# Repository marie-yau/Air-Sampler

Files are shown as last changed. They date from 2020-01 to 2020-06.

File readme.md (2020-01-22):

# Next-Generation Air Sampler Project

This project seeks to design a lightweight, programmable air sampler.

The sampler will be constructed on the
[Raspberry Pi](https://www.raspberrypi.org/)
platform.

The sampler will allow for the automated operation of an air pump and any number of three-way solenoids.

Its immediate use is for tracer gas experiments in which bags will be used to capture samples of air outdoors or in buildings.

The project is led in parts by Michael Sohn (Principal Investigator),
Woody Delp,
David Lorenzetti,
Randy Maddelena,
Marion Russell,
and
Marie Yau.

The project is supported in part by the Defense Threat Reduction Agency.

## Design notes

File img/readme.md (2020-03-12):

# Circuit Diagrams

This folder contains circuit diagrams for the setup of the sampler and of any additional modules of Raspberry Pi.

The files with ```.fzz``` extension can be opened using [Fritzing](https://fritzing.org/home/), a software used for the creation of diagrams.

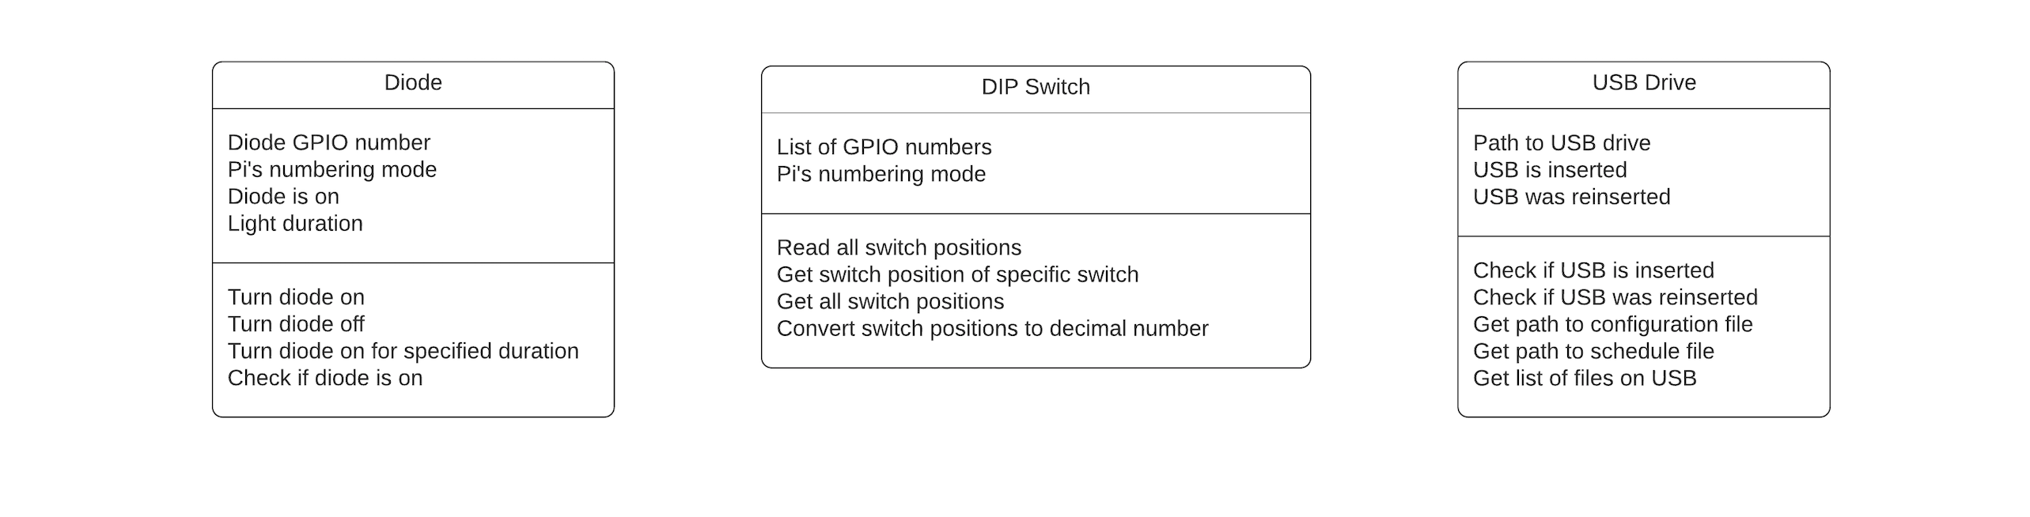
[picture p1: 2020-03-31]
img/UML_hardware.png

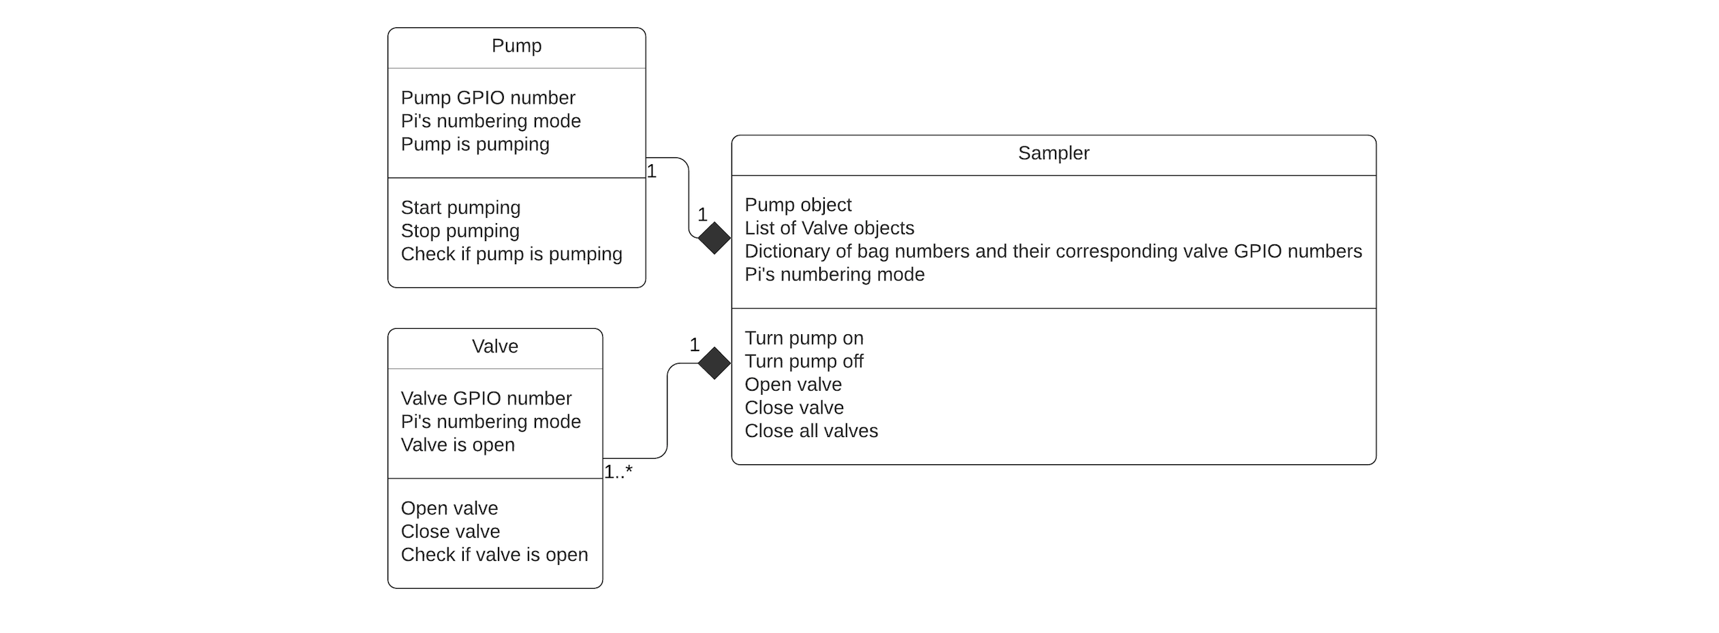
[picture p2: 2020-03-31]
img/UML_sampler.png

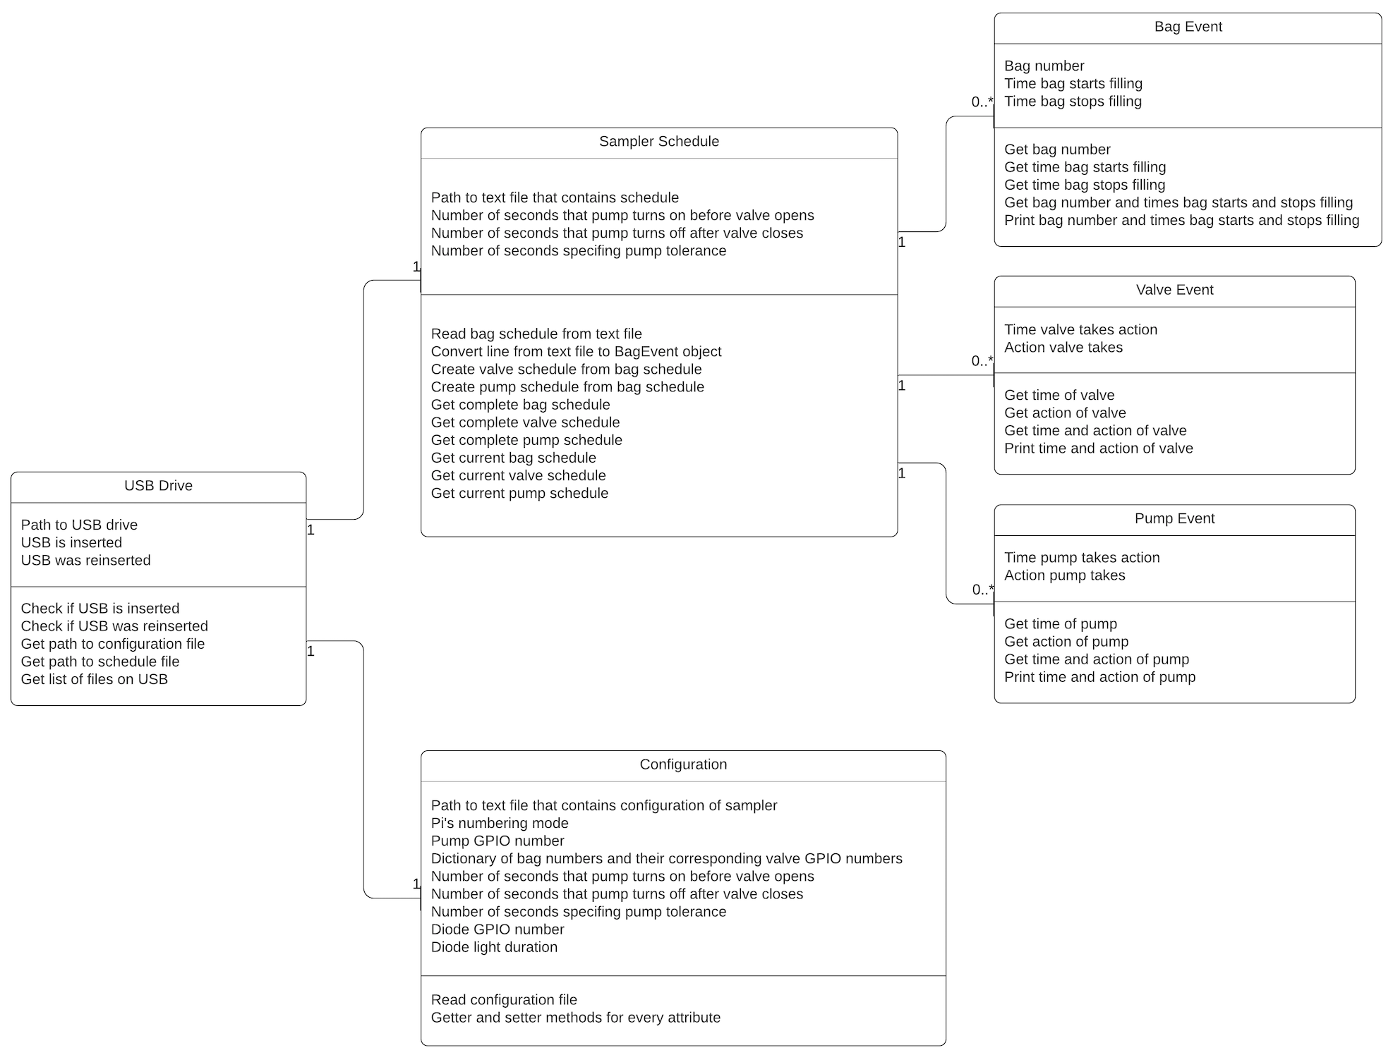
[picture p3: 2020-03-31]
img/UML_files.png

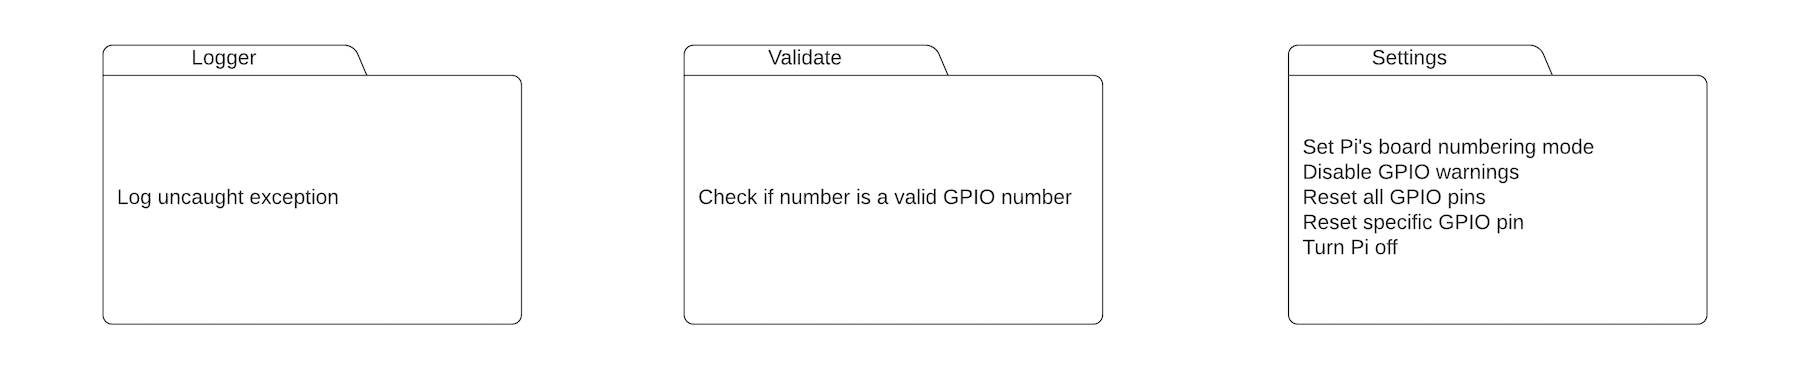
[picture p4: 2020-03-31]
img/UML_package.png

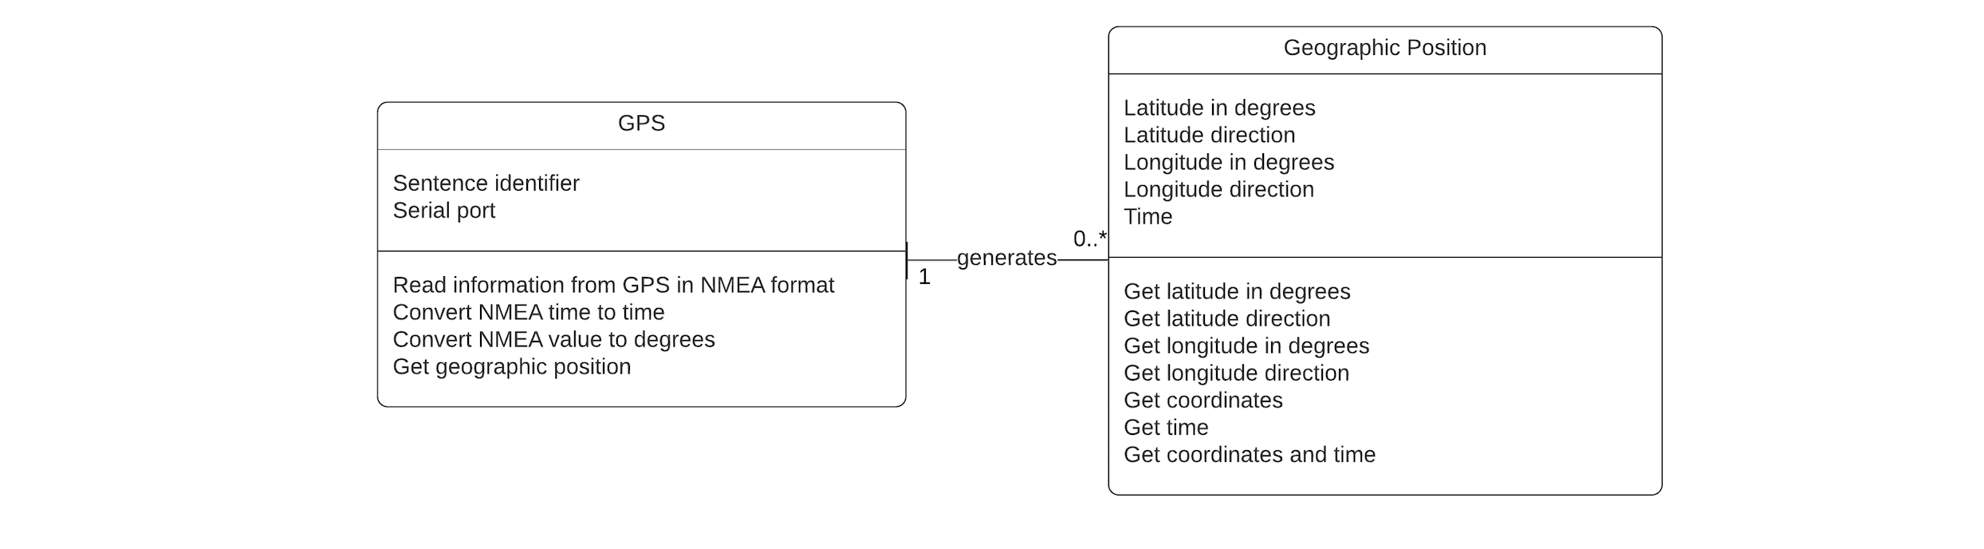
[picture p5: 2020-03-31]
img/UML_GPS.png

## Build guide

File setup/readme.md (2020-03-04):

# Sampler setup

This folder contains instructions for setting up the hardware and software of the sampler. 

The instructions for the setup of the final version of the sampler are in the ```final_setup.md``` file. 

Previous prototypes included other Raspberry Pi modules and hardware that are not included in the final version of the sampler. Instructions for setup of these components are included in separate files for reference.

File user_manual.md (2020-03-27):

# User Manual

This application is a software tool for operating airsampler that takes air samples according to the specified schedule. 

## Understanding how airsampler works
Refer to the diagram below to understand how the airsampler works.
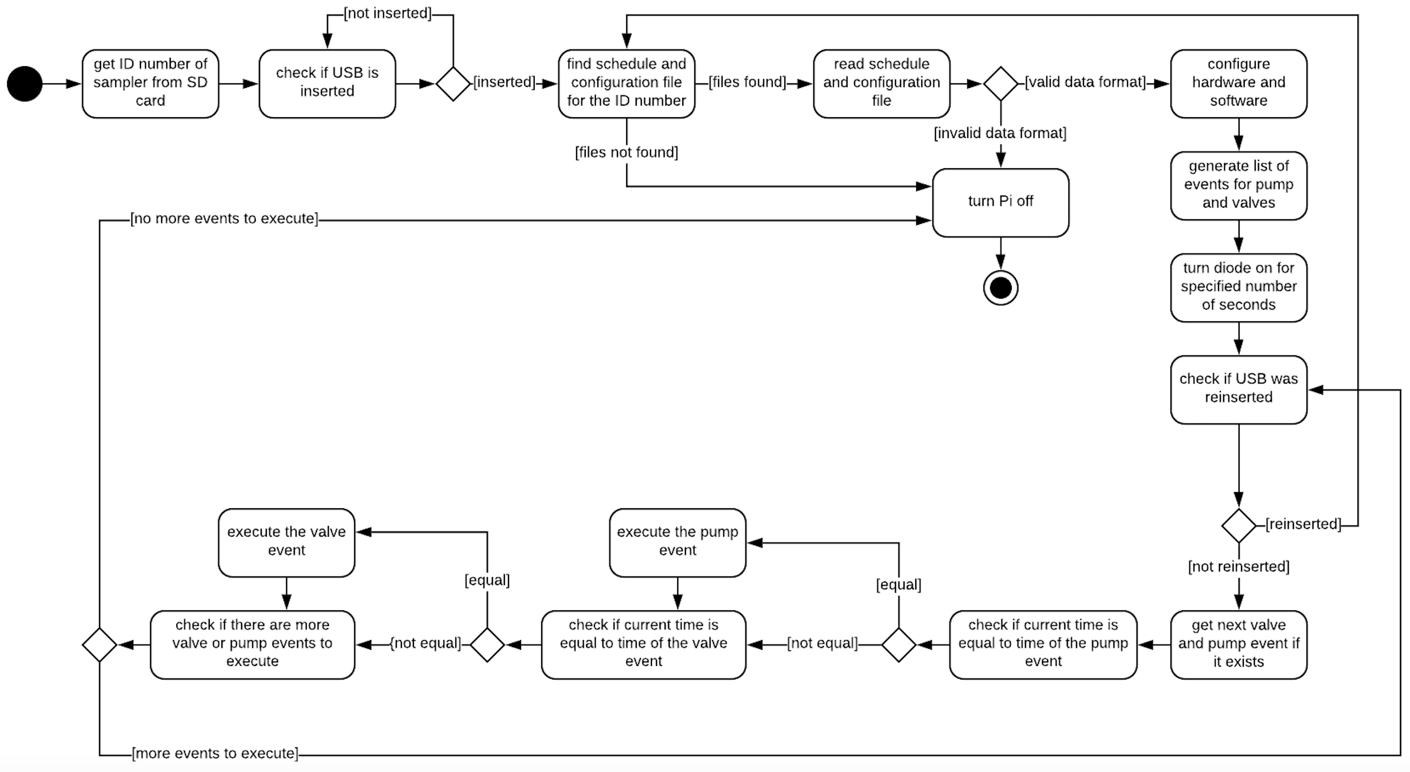
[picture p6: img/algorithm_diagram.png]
Algorithm


## Schedule file format
Schedule file contains information necessary to take the air samples.

Format requirements:

- The file name must be ```<sampler ID>_schedule.txt```. For example, if the sampler has ID 90, its schedule file is ```90_schedule.txt```.
- The file must contain header. The first line of the file must be ```Bag number, Start filling, Stop filling```. No white spaces in the begging or in the end of line are allowed.
- Lines that start with ```#``` are considered a comment. ```#``` must be the first character on the line and no white spaces are allowed in front of it.
- Lines containing information about taking a sample must be in the format ```<bag number>, <time start filling>, <time stop filling>```. For example, ```3,  2020-03-06 11:38:00,  2020-03-06 11:38:30```. 
	- Additional white spaces may be included in this line as long as they are not in ```2020-03-06``` and ```11:38:00```.
	- The time must contain full year (```2020```, not ```20```). Month and day don't have to be padded with zeros. Hour also doesn't have to be padded with zeros.
- Bag number may be padded with zeros.
- No blank lines, lines that don't start with ```#``` and lines that aren't in format ```<bag number>, <bag starts filling>, <bag stops filling>``` are allowed anywhere in the file.
- Lines containing a schedule for a sample don't have to be ordered in any way (for example, it is not necessary to order them according to the ```Bag number``` or ```Start filling```.
- The ```Start filling``` time must be earlier than ```Stop filling``` time.

Also note that times for multiple samples can overlap and there can be multiple samples for one bag.

An example of the required schedule file:

	Bag number, Start filling, Stop filling
	3,  2020-03-06 11:38:00,  2020-03-06 11:38:30
	1,  2020-03-06 11:38:15,  2020-03-06 11:38:40
	# this is a comment
	2,  2020-03-06 11:39:15,  2020-03-06 11:39:35
	1,  2020-03-06 11:40:00,  2020-03-06 11:40:30

## Configuration file format
Configuration file contains information necessary to configure hardware and software of airsampler.

The configuration file contains the following information:

- ```Numbering mode```
	- Identifies the board numbering mode. It must be either ```BCM``` (the GPIO is identified by the number that is used by Broadcom, the manufacturer) or ```BOARD``` (the GPIO is identified by the position on the Pi).
- ```Bag numbers to valve pin numbers```
	- Links each bag number to the GPIO number that the valve that controls airflow into the bag is connected to.
- ```Pump pin number```
	- Identifies the GPIO number that the pump is connected to.
- ```Diode pin number```
	- Identifies the GPIO number that the diode is connected to.
- ```Diode light duration```
	- Specifies the number of seconds the diode stays turned on to indicate that the hardware and software was set up correctly.
- ```Number of seconds pump starts pumping before valve opens```
	- Specifies the number of seconds the pump starts pumping before a valve opens.
- ```Number of seconds pump continues pumping after valve closes```
	- Specifies the number of seconds the pump continues pumping after a valve closes.
- ```Pump time off tolerance in seconds```
	- Specifies the number of seconds. If pump is scheduled to turn off for less than the specified number of seconds, the pump will continue pumping.

Format requirements:

- The file name must be ```<sampler ID>_config.txt```. For example, if the sampler has ID 90, its configuration file is ```90_config.txt```.
- No additional lines (blank lines included) are allowed anywhere in the file. 
- The headers for the lines (```Numbering mode```, ```Bag numbers to valve pin numbers```, etc) have to be exactly in the same format as listed below. 
- The headers can be in any order.
- There may be white spaces in the beggining and in the end of each line.
- The line below the ```Bag numbers to valve pin numbers``` line must be in format ```<bag number 1> : <GPIO number 1>, ..., <bag number n> : <GPIO number n>```. For example, ```1: 19, 2: 4, 3: 22```. All whites spaces on this line are ignored.

An example of the required configuration file:

	Numbering mode
	BCM
	Bag numbers to valve pin numbers
	1: 19, 2: 4
	Pump pin number
	13
	Diode pin number
	17
	Diode light duration
	3
	Number of seconds pump starts pumping before valve opens
	5
	Number of seconds pump continues pumping after valve closes
	5
	Pump time off tolerance in seconds
	10

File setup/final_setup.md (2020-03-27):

# Hardware setup

## Create circuit for the sampler
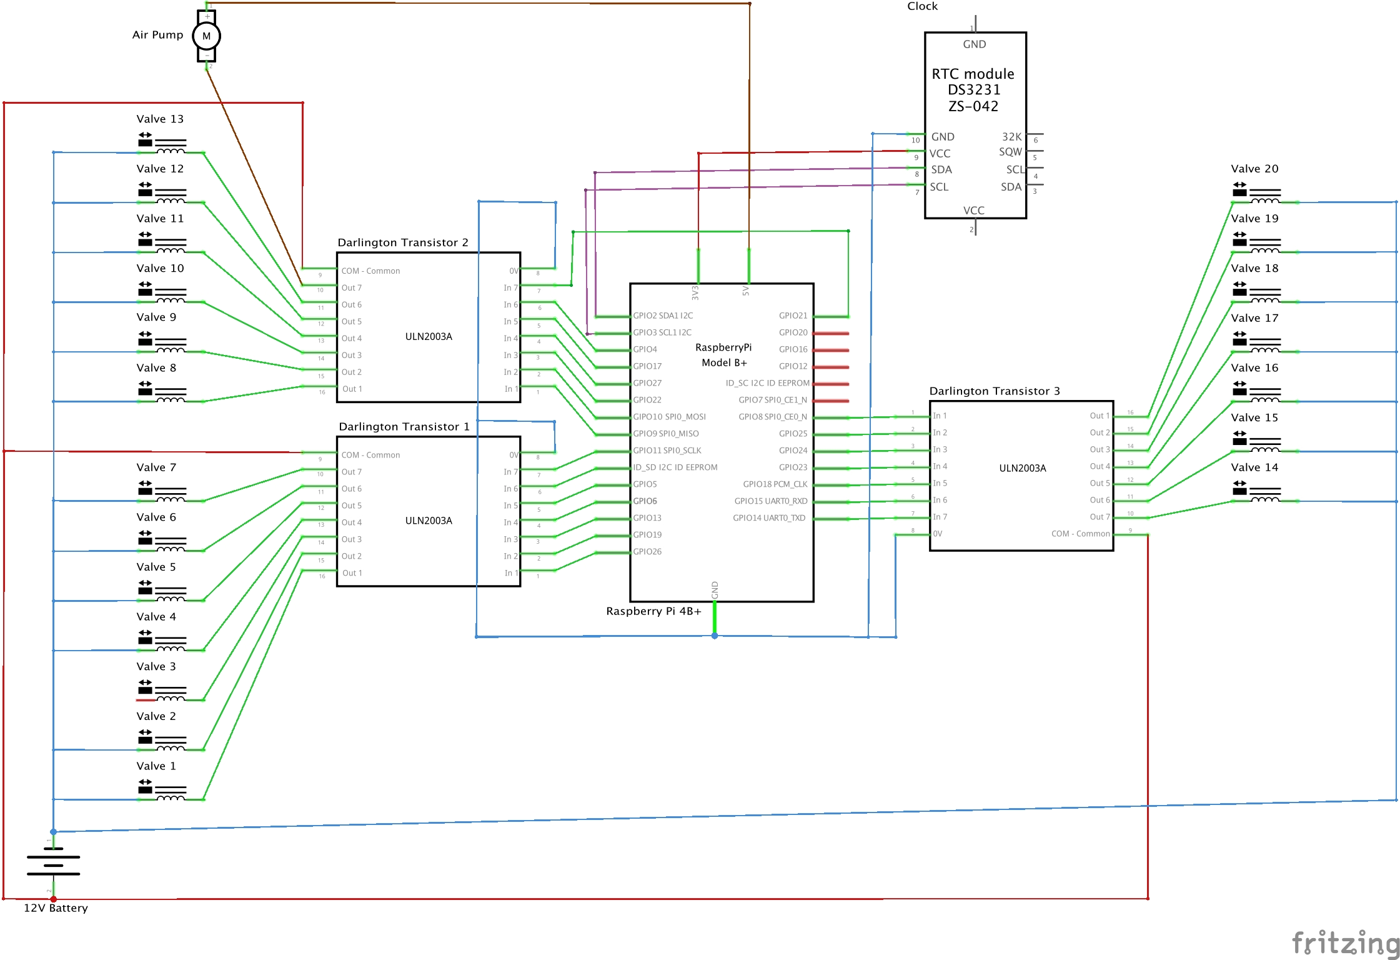
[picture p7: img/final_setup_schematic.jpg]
Circuit diagram for the sampler


## Set up Raspberry Pi
### Using monitor and keyboard
 1. Install [balenaEtcher](https://www.balena.io/etcher/).
 2. Download latest version of [Raspbian](https://www.raspberrypi.org/downloads/raspbian/) operating system.
 3. Connect SD card to the computer and mount the Raspbian image to the SD card using balenaEtcher.
 4. Insert SD card to the Raspberry Pi.
 5. Connect monitor, mouse, keyboard, Wi-Fi module and charger to the ports of Raspberry Pi.

### Headless using ethernet cable
1. Mount the Raspbian image to the SD card using balenaEtcher.
2. Create `ssh` file in `boot` drive, to allow ssh.

        touch /Volumes/boot/ssh
    
3. Connect one end of ethernet cable to Raspberry Pi and the other end to your computer.
4. Find the IP address of Raspberry Pi using `ping` command.

        ping raspberrypi.local

5. ssh into the Raspberry Pi. Replace `pi` with your Pi's username (default username is `pi`) and `IP` with the IP address.

        ssh pi@IP
    
    Answer `yes` to question `Are you sure you want to continue connecting?` and enter your password (default password is `raspberry`).

## Configure real time clock

### Circuit

Mount the real time clock to Raspberry pi.

If you have real time clock DS3231 Model B (the one with 6 pins), you can't mount it directly on GPIO pins because DS3231's pins are not in correct order.

* Vin/VCC connects to pin 1 (3.3V)

* GND connects to pin 6

* SDA connects to pin 3

* SCL connects to pin 5

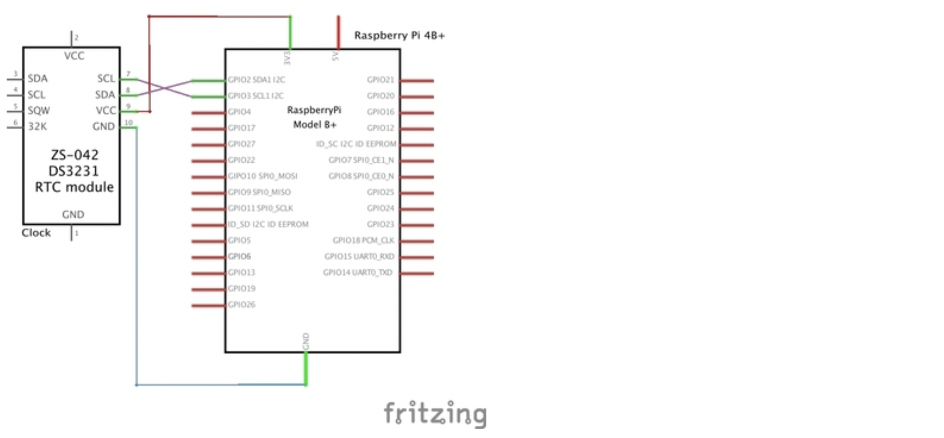
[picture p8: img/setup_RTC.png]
RTC circuit


### Configuring the real-time clock

1. After the circuit is ready, open the command line and type

        >> sudo i2cdetect -y 1
	
    If the output is
    `Error: Could not open file '/dev/i2c-1'`
    or
    `/dev/i2c/1': No such file or directory`,
    try the following:
	
    * Open file /etc/modules.
	
            >> sudo nano /etc/modules
		
        Check if it contains i2c-bcm2708 and i2c-dev. If not, add them:
		
            i2c-bcm2708
            i2c-dev
		
        Save and exit the file (Ctrl + X).
		
    * Open /etc/modprobe.d/raspi-blacklist.conf
	
            >> sudo nano /etc/modprobe.d/raspi-blacklist.conf
		
        Check if i2c-bcm2807 is blacklisted. If it is, add # to the start of line.
		
            # blacklist i2c-bcm2708
		
    * Run `sudo raspi-config`.
        Select `5 Interfacing Options`.
        Then select `I2C` and enable it.
    * Restart the computer after doing any of the steps above.

            sudo shutdown -h now

2. After `>> sudo i2cdetect -y 1` is working,
    Raspberry Pi should detect the device is plug in.
    It should show 68 in row 60 and column 8.

3. Open file /etc/modules.

        >> sudo nano /etc/modules
	
    Add rtc-ds3231 to the file.
	
        rtc-ds3231

    Save and exit the file (Ctrl + X).

4. Open file /boot/config.txt.

        >> sudo nano /boot/config.txt
    
    Scroll to the bottom of the document and add dtoverlay-i2c-rtc,ds3231 to the file.
	
        dtoverlay-i2c-rtc,ds3231

5. Remove the fake power clock.

        >> sudo apt-get -y remove fake hwclock
        >> sudo update-rc.d -f fake-hwclock remove

6. Open file /lib/udev/hwclock-set.

        >> sudo nano /lib/udev/hwclock-set
	
    Comment the following lines at the beginning of the document.
    
        # if [ -e /run/systemd/system ] ; then
        # exit 0
        # fi
 
7. Reboot the Raspberry Pi.

        >> reboot
	
8. Check if Raspberry Pi has the right date and time.
    The `date` command prints the time that Raspberry Pi got from the Internet,
    and `sudo hwclock -r` prints the time that the real time clock has.
    
	    >> date; sudo hwclock -r
	
    If the outputted times don't match, update the hardware time to the Internet time:

        >> sudo hwclock -w

## Run driver.py script automatically at startup

1. Connect Raspberry Pi to Wi-Fi.
2. Save all files from this repository to `/home/pi/Desktop/sampler`.
3. Install Supervisor.

        >> sudo apt-get install -y supervisor

4. Start Supervisor service.

        >> sudo service supervisor start

5. Create the configuration information.

        >> sudo nano /etc/supervisor/conf.d/sampler.conf

6. Type the configuration information to the file and save it (Ctrl + X).

        [program:sampler]
        command=python3 driver.py
        directory=/home/pi/Desktop/sampler
        autostart=true
        autorestart=true

7. Include the new configuration file.

        >> sudo supervisorctl reread

8. Update Supervisor.

        >> sudo supervisorctl update

9. Check if the service started.

        >> sudo supervisorctl

    It should return something similar to `sampler RUNNING pid 1008 0:37:39`.

To stop the script:

    >> sudo supervisorctl stop sampler

To start the script:

    >> sudo supervisorctl start sampler

## Set ID number on SD card
1. Create a hidden file ```.ID.txt``` in the home directory. To verify that you are in the home directory, use command ```pwd```. It should return ```/home/pi```. 

        touch .ID.txt

2. Write the ID number into the file. For example, if the ID number is 90, open the file in the editor (```nano .ID.txt```), write 90 into the file and save it (```Ctrl+X```).

3. Give the file read-only permission. To verify that the permission was changed, use command ```ls -l -a```. The permission under ```.ID.txt``` should be ```-r--r--r--```.

        chmod 444 .ID.txt

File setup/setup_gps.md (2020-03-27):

# Configure GPS

## Circuit
The GPS module used was E218213 by adafruit.

* Vin connects to pin 17 (or any other 3.3 V pin)
* GND connects to pin 39 (or any other ground pin)
* RX connects to pin 8
* TX connects to pin 10

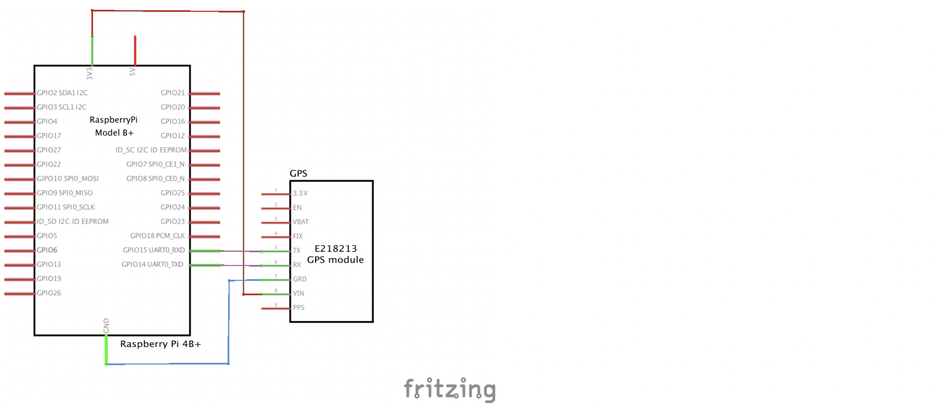
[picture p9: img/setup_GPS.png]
Circuit diagram for the sampler

## Configuration
1. Connect Raspberry Pi to Wi-Fi.
2. Enable serial interface.

        >> sudo raspi-config
    
    Go to `5 Interfacing Options`.
    Then go to `P6 Serial`.
    
    Answer `No` to question `Would you like a login shell to be accessible over serial`.
    
    Answer `Yes` to question `Would you like the serial port hardware to be enabled?`.
    
    Select `Finish` and `Restart`.
    
3. Modify the configuration file.

        >> sudo nano /boot/config.txt

    Scroll down and type
    
        dtoverlay=pi3-disable-bt
        core_freq=250
        enable_uart=1
        force_turbo=1
    
4. Backup cmdline.txt file.

        >> sudo cp /boot/cmdline.txt /boot/cmdline.txt.backup

5. Edit cmdline.txt file.

        >> sudo nano /boot/cmdline.txt

    If the file contains `console=serial0,115200`, delete it.
    
    Delete `root=PARTUUID=5e3da3da-02` and replace it with `root=/dev/mmcblk0p2`
    
6. Reboot Pi.

        >> sudo reboot

7. Stop and disable the serial ttyS0 service.

        >> sudo systemctl stop serial-getty@ttySO.service
        >> sudo systemctl disable serial-getty@ttySO.service

8. Reboot Pi.

        >> sudo reboot

9. Enable the serial ttyAMA0 service.

        >> sudo systemctl enable serial-getty@ttyAMA0.service

10. Verify that the service was enabled.

        >> ls -l /dev

    The service `serial0 -> ttyAMA0` should be in the outputted list of services.

11. Install minocom package that is used to connect to the GPS module.

        >> sudo apt-get install minicom

12. Install pynmea2 library that is used to parse the received data.

        >> sudo pip install pynmea2

13. Verify that the GPS module is working.

        sudo minicom -D /dev/ttyAMA0 -b 9600

    Press Ctrl + A. After that press X and then press Enter key.

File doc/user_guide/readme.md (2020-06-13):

# Directory *user_guide*

User Guide for the `airsampler` project.

This directory contains the source files that define the User Guide.
These files get converted to a more readable form using
[Sphinx](https://www.sphinx-doc.org).

The source files are written in the
[reStructuredText](https://www.sphinx-doc.org/en/master/usage/restructuredtext/basics.html)
format.
In addition to the standard reST syntax,
Sphinx adds a number of
[custom roles](https://www.sphinx-doc.org/en/master/usage/restructuredtext/roles.html)
and
[custom directives](https://www.sphinx-doc.org/en/master/usage/restructuredtext/directives.html).

Sphinx can convert the documentation into several final formats,
including hyperlinked web pages and PDF documents.

## Directory contents

Files:

+ `make.bat`
    + Driver for Sphinx at the DOS command prompt.
    + This file was generated by Sphinx, and lightly hand-edited.
+ `Makefile`
    + Driver for Sphinx at the Unix terminal prompt.
    + This file was generated by Sphinx, and lightly hand-edited.

Subdirectories:

+ `source`
    + Files containing the documentation contents.

## Running Sphinx in a Unix terminal

If Sphinx is installed under a Python virtual environment,
start that environment.
For example:

    $ source  venv_sphinx/bin/activate

See the installation instructions below for more information.

Invoke Sphinx using the provided makefile:

    $ make  <target>

where `<target>` is one of the targets that
[`sphinx-build` understands](https://www.sphinx-doc.org/en/master/usage/builders/index.html).
Useful targets include:

+ `html`
    + Standard builder for hyperlinked HTML pages.
    + Also available: `singlehtml`,
        to combine everything into a single page.
+ `latexpdf`
    + Make a PDF, using LaTeX.
+ `epub`

Note `make` may fail with a message like:

    $ make html
    /bin/sh: sphinx-build: command not found

This indicates that `make` cannot find `sphinx-build` on the path.
Check to ensure that Sphinx is installed,
for example by reviewing the modules listed by:

    $ python -m pip list

If Sphinx is not installed,
you may need to start a virtual environment that has it.
See the installation instructions below.

## Installing Sphinx

Set up a Python virtual environment.
For example,
to create a virtual environment in directory `venv_sphinx`:

    $ python3  -m pip  install --upgrade pip
    $ python3  -m venv  venv_sphinx

Tips:

+ Whichever Python interpreter you use to create the virtual environment,
    is the one you will end up using whenever you run that environment.
+ *Do not* set up the virtual environment in a version-controlled directory,
    or you will have to fight your version control system to convince it
    not to track the interpreter.
+ When you start up the virtual environment,
    it will alter the Unix prompt.
    To control the new part of the prompt,
    use the `--prompt` switch when creating the virtual environment:

        $ python3  -m venv  --prompt py_sphinx  venv_sphinx

After the virtual environment is installed,
activate it.
On Unix:

    $ source  venv_sphinx/bin/activate

On DOS:

    $ venv_sphinx/bin/activate.bat

If successful,
you should see the modified command prompt.

Then install Sphinx:

    $ python  -m pip  install --upgrade Sphinx

Notes:

+ Once you are in the virtual environment,
    you can just invoke `python`,
    and you will get whichever interpreter you used to create the environment.
+ To exit the virtual environment:

        $ deactivate

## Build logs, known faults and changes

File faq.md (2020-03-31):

# Frequently Asked Questions

## Log files

### Where can I find a specific log file?
All log files are saved in ```/home/pi/Desktop/sampler_logs/``` folder. 

A new log file is generated every time the program is run (that is every time you turn on the Pi) and its name is the time the program started. For example, if the program started at 2:30 pm on March 26 2020, the name of the log file is ```2020-03-26 14:30:00```.

### What does the program log?
The program logs:

- actions of pump, valves and diode
- content of configuration file
- content of schedule file and the all schedules that were generated based on the file
- ID number of sampler
- insertion of a new USB drive
- start and end of the program
- reset of GPIO pins and disablement of GPIO warnings
- type of exception and place where it occured

## USB

### How long does the USB needs to be inserted in Pi?
The Pi should detect and read the files from the USB drive within a second. The diode will light up after the USB drive is detected and files are correctly read.

### Can you insert multiple USBs to the Pi?
No. You are only allowed to insert one USB drive that contains the configuration and schedule file for the sampler.

### I inserted a USB with files in an incorrect format to the Pi, ejected it, corrected the files and inserted the USB to the Pi again with the files in the correct format. It is not working. What's wrong?
After you inserted a USB with files in an incorrect format, the program threw an exception and turned the Pi off. Therefore, the Pi was no longer running when you inserted the USB with files in the correct format to the Pi.

To execute the schedule, turn the Pi on to start the program again and insert the USB.

### Can you SSH into the Pi and change the schedules on the USB drive without ejecting it?
No. If you change the schedule or configuration file by SSHing into the Pi, the program won't read the files again. To change schedule or configuration of sampler, you have to eject the USB and insert it again or you can restart the Pi.

### Can the USB contain some other files and folders?
Yes.

### Can schedule and configuration files be stored in a folder on the USB drive?
No. The schedule and configuration files have to be stored in the root directory of the USB drive.

## Raspberry Pi 

### If I turn the Pi off and back on again, will it remember its schedule and continue executing it?
No. You have to insert the USB drive to the Pi again.

### I SSHed into the Pi and noticed that the its time is incorrect. How do I fix it?
The Pi's time is set to UTC time (Coordinated Universal Time), so the time may be off by hours depending on your time zone. If the minutes and seconds are off, you have to connect the Pi to the Internet and it will be automatically updated.

### Where can I find the sampler ID number?
The sampler ID number is in ```/home/pi/.ID.txt``` file. Type ```nano /home/pi/.ID.txt``` into the command line to see the ID number.

### When will Pi turn itself off?
The Pi turns itself off when the program finishes the schedule or when the program throws an exception or error (e.g. because the files in are in incorrect format or are missing).

### How do I know that Pi is turned off?
When Pi is turned off, the red light on the motherboard is on and the green light is off.

## Schedule and configuration files

### What happens when files are not in the correct format?
The program throws an exception or error, writes its details into the log file and turns of the Pi.

### How can I change the schedule?
Eject the USB drive from the Pi, change the schedule file on the drive using your computer and insert it back to the Pi.

### Can I change the schedule after the current schedule finished executing?
Since the Pi turned itself off when the current schedule finished executing, you have to eject the USB drive, change the schedule, turn the Pi on and insert the USB drive with the new schedule back to the Pi.

### What happens when I insert a USB with an old schedule to the Pi?
If the schedule contains only samples that were supposed to be taken in the past (e.g. all samples were scheduled to be taken during day 2020-03-19 and today, it is 2020-04-20), the program will throw an exception and turn the Pi off.

### I inserted/reinserted a USB with a schedule to the Pi late. Some samples were already supposed to be taken and some samples should be in progress right now. What is going to happen?
All samples that are supposed to be in progress right now won't be taken. For example, sample starting at 11:30:00 and ending at 11:32:00 will not be taken if the USB drive is inserted to the Pi (or the Pi itself is turned on) at 11:31:00. Also, note that the configuration file specifies the number of seconds the pump starts pumping before the valve opens. If it the pump was already supposed to be pumping when you turned on the Pi/inserted the USB drive, the sample will not be taken. For example, let's say that a sample starts at 11:30:00 and ends at 11:32:00. If you set the number of seconds the pump starts pumping before the valve opens to 15 and now it is 11:29:55, this sample will not be taken because the pump was supposed to start pumping at 11:29:45.

If the schedule contains only some samples that that are supposed to be in progress right now/were already supposed to be taken, the program will execute the future samples.

## Hardware

### What does it mean when the diode lights up?
It means that the schedule and configuration files are in the required format and everything is set up to execute the schedule.

### I inserted the USB to the Pi and the diode lighted up. After some time, I came back to check up on the sampler, the diode was no longer on. Does it mean there was a problem?
There wasn't any problem. The diode lights up only for the number of seconds specified in the configuration file.

### The diode didn't light up after I inserted the USB to the Pi. What's wrong?
There are several possibilities:

- The schedule and configuration files 
    - aren't in the required format
    - are missing
    - don't have the corrent name
    - aren't stored in the root location in the USB
- More than one USB is inserted in the Pi.
- Pi wasn't turned on (the green and red lights on the motherboard didn't light up/blink).

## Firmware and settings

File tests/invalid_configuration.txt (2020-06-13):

Diode light duration
0
Number of seconds pump starts pumping
-2
Number of seconds pump continues pumping after valve closes
0
Pump time off tolerance in seconds
7

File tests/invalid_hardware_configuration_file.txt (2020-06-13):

Identification number
-23
Numbering mode
broadcast
Bag numbers to valve numbers
1: 19, 2: 13
Pump pin number
13
Diode pin number
-1

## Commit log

2020-01-17 Added Maria's function for managing the dip switch. Also renamed the file.
2020-01-18 Conditioned DIP switch pins via a for-loop.
2020-01-18 Read DIP switch pins via a for-loop.
2020-01-18 Broke out reading of DIP switch pins into own list comprehension.
    + Prefer list comprehension to repeated appends to list.
    + This prepares for possibly separating conditioning step into its own function,
    as suggested in a related TODO item.
2020-01-21 Added folder for sampler application, named mark1.
2020-01-22 dip switch as a class
2020-01-22 Added comments / TODO items on dip switch reader class.
2020-01-22 dip switch update
2020-01-22 Added TODOs for dip switch code, while reading GPIO module documentation.
2020-01-23 .idea/sampler.iml edited online with Bitbucket
2020-01-25 corrected dip switch and added comments
2020-01-25 added function for setting board numbering mode
2020-01-26 new class for geographic position of sampler
2020-02-01 class for operating pump
2020-02-01 update class for operating pump
2020-02-01 class for operating the valve
2020-02-04 new format of text file, turn pump ahead of time
2020-03-10 add diagrams for hardware setup
    [final_setup.fzz]
2020-03-10 added circuit diagram
2020-03-10 added circuit diagram to readme
2020-03-10 added circuit diagram for real time clock
    [setup_RTC.fzz]
2020-03-10 added circuit diagram for RTC
2020-03-10 add readme for circuit diagrams
2020-03-24 implemented logging and threading for diode
2020-03-24 implemented threading for diode
2020-03-25 get the duration for the diode light from the configuration file
2020-03-25 handled case - no current events to execute
2020-03-27 logged ID number of sampler
2020-03-27 moved diagrams to different folder
    [final_setup.fzz, setup_GPS.fzz, setup_RTC.fzz]
2020-05-31 Ban overlaps of samples in schedule
2020-05-31 Added code that checks if there is at least one sample scheduled to be taken in the future
2020-06-13 Added tests containing valid and invalid input files
    [invalid_configuration.txt, invalid_hardware_configuration_file.txt, valid_configuration.txt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]
